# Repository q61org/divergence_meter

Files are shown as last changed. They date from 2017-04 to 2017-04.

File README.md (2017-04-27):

# Divergence Meter Project (by q61.org)

This is yet another divergence meter project.

This project tries to make a divergence meter that look just like the one in the Steins;Gate anime series, by implementing the following features:
- Using tip-less, flat-top nixie tubes (NL902) that look similar to the tubes in the anime.
- Compact dimensions: so that you can hold it on your hand like Suzuha does, and so that you can use the meter for cosplaying.
- A built-in, rechargeable battery; so that Suzuha can take it out of her bag while it is displaying a divergence value.

The result, a completed divergence meter can be seen below.

divergence meter with dr pepper
divergence meter with an anime screen capture

## Files in This Repository

This repository contains schematics, PCB files and a firmware of the divergence meter. Chassis design is left as an exercise to makers (forks and pull requests are welcome!).

The divergence meter is composed of 3 PCBs, and there are 3 PCB filesets in this repository:
- dm_control: A board that controls everything; the motherboard.
- dm_nixiebrd: A serial-to-parallel converter board with nixie drivers. This is the board where nixie tubes are mounted on, and stacks on top of dm_control board.
- dm_topboard: A perfboard-like board that goes on top of the divergence meter. This board does not have any electrical functions, but adds very much to the aesthetics.

dm_control board has a microcontroller, and its firmware is in the following subdirectory:
- dm_firmware: Firmware for dm_control board.

## License

Schematics and PCB, and firmware are licensed under different licenses:
- Schematics and PCB files are licensed under [Creative Commons BY-SA 4.0](https://creativecommons.org/licenses/by-sa/4.0/).
- Firmware is licensed under the BSD license. 

Please see README.md and LICENSE files in respective directories.

## See Also

This project was inspired by following projects:
- [Divergence Meter Project](http://www.mindspring.com/~tomtitor/)
- [世界线变动率探测仪 | Divergence Meter](http://www.nixieclock.org/?cat=219)

## Disclaimer

There is no warranty, expressed or implied, associated with files in this project. Especially there is a high voltage shock hazard which can kill you. Use at your own risk. 

## Author

Kouichi Kuroi (q61.org)
- Twitter: https://twitter.com/q61501331

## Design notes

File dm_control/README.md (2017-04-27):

# dm_control Board

This board is the motherboard of the divergence meter.

The board has the following functionalities on board:
- Lithium-ion battery charger
- 3.7V to 180V DC/DC boost converter
- 3.7V to 3.3V DC/DC buck converter
- Microcontroller (ATmega328P) that controls nixie tubes
- USB to UART converter (FT231X)
- Accurate RTC (DS3234)

## About Power Supplies

You must be careful about power supplies on this board,
as they can be hazardous to you in some ways.

### Lithium-ion Battery Charger

This board has an MCP73831 battery charger chip. You can connect
a lithium-ion battery to connector P2 to make the divergence meter
free from power cords. 
However, you must be careful about what battery you use.

The MCP73831 chip controls only charging from the USB connector; 
it automatically stops charging when the battery is full, 
but it does not stop discharging when the battery is empty.

**There is no overdischarge protection on this board.**
Therefore you **MUST** use a battery with a built-in
overdischarge protection. **DO NOT USE RAW CELLS!**

Connector P2 is a 2-pin PH connector. This is a standard connector
for commonly available pouched LiPo cells. These batteries
usually have protection circuits, but double-check it before 
you actually use one.

### DC/DC Converters

This board has two DC/DC converters on board, a boost converter
that generates 180V for igniting nixie tubes, and a buck converter
that generates 3.3V for microcontroller and other digital chips.

The one that can harm you is, obviously, the boost converter.
Although it can only output some milliamps continuously, it has
2uF of smoothing capacitors (C14 and C15). 
When the converter is powered up without any load, it can charge 
the capacitors to their maximum capacity. This charge will remain 
in the capacitors after the converter is powered down, 
and when you touch them, all the charge can go through you.
This can be very bad.

When handling this board, always make sure that the power is off,
and that capacitors are discharged.

## Disclaimer (again)

There is no warranty, expressed or implied, associated with files in this project. Especially there is a high voltage shock hazard which can kill you. Use at your own risk. 

## License

Schematics and PCB files are licensed under Creative Commons BY-SA 4.0.

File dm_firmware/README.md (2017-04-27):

# dm_firmware

This is a firmware for ATmega chip on dm_control board.

It is intended to be compiled with Atmel Studio 7, but you can also compile it with standard avr-gcc (with some command line options).
You can first burn a bootloader (such as Arduino or Optiboot) onto the ATmega so that firmware upgrade can be done via USB.

## Fuse Settings

This firmware does not handle WDT. WDT must be turned off.

As the firmware controls multiplexing of nixie tubes by 8.192kHz clock
from the RTC, it isn't very strict about clocking the cpu itself.
However, if you use a bootloader, you should set it to use the ceramic
resonator on dm_control board, so that UART communication has less errors.

If you use Arduino bootloader, the following fuse settings is good:
- Extended bits: 0xFD
- High bits: 0xDA
- Low bits: 0xFF

## Functions

The firmware has very limited set of functions.

When you power up the meter, it does a lamp check (cycling from 0 to 9 and dp),
and then displays a divergence value.

When you press SW2 or SW3, the display changes to next preset divergence value.

When you press SW5, it shuffles the display for about 10 seconds and then
goes back to the divergence value.

When you press SW4, it displays current voltage of the battery. When you press SW4 again while shoing the voltage, the meter goes into a demo mode.
In demo mode, divergence value changes every about 20 seconds.

## License

Files in this directory are licensed under BSD license.

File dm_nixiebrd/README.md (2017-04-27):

# dm_nixiebrd Board

This is a serial-to-parallel converter board with nixie drivers.
It is designed for NL-902 or NL-842 nixie tubes.

This board needs a high voltage power to ignite nixie tubes. 
Be careful when handling high voltages. It can kill you.

* How to Connect With dm_control Board

The left half of this board is designed to match with the dm_control board.
You can solder pin headers to P1-P3, and they mate with P4-P6 of dm_control board.

## Mounting Nixie Tubes

This board is designed to use discrete pin sockets to mount nixie tubes.
The sockets should be a "Socket Pin" type which accept 1mm pins for 
socket side and which have 0.5mm pin for pin side.

If you search eBay with keywords "1mm nixie pin" you will get good examples.
And in fact I used pins from eBay for my first divergence meter.

Of course it is also good to modify the board so that it fits any sockets
or direct soldering you would want to use.

## Changing Nixie Tubes

As well as mounting method you can change nixie tubes that this board mounts.
If nixie tubes are rated for nominal currents out of 3mA-4mA range, 
you should change values of R2 and R12 resistors.

## Disclaimer (again)

There is no warranty, expressed or implied, associated with files in this project. Especially there is a high voltage shock hazard which can kill you. Use at your own risk. 

## License

Schematics and PCB files are licensed under Creative Commons BY-SA 4.0.

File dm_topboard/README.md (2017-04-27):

# dm_topboard Board

This is a perfboard-like board that goes on top of a divergence meter.

The board is mostly a 3.15mm-pitch perfboard, except that it has the 
following features to accomodate parts for making it look like the
perfboard on top of the divergence meter in the anime:
- 8 holes with 16mm diameter, where pins of nixie tubes go through (to dm_nixiebrd board).
- 2 sets of 16x 2.54mm-pitch holes in the back of the board, where 16-pin DIP ICs go in.
- 1 pair of 5mm-pitch holes in the front of the board, where a coin-shaped capacitor (or anything else that looks like it) goes in.

Mounting holes are for M2.6 screws.

## License

Files in this directory are licensed under Creative Commons BY-SA 4.0.

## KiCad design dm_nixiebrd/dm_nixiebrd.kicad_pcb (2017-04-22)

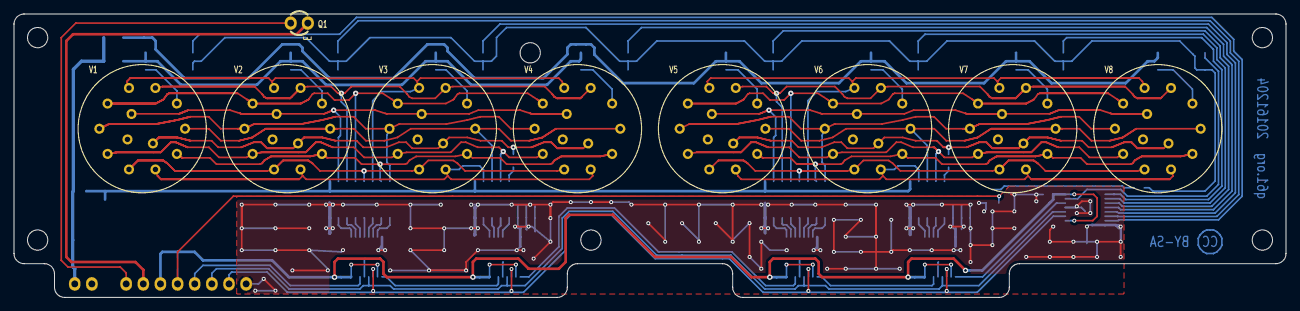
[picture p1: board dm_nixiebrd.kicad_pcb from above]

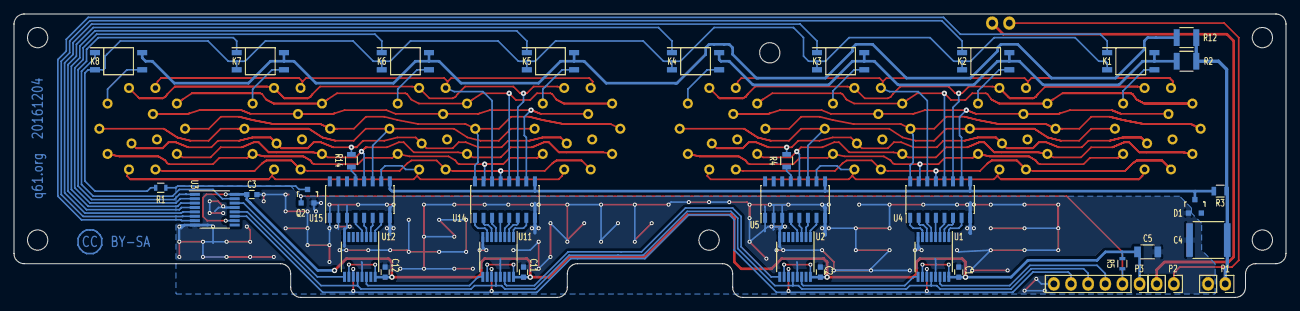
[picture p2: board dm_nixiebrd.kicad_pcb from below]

Board: 2 copper layers, 188.5 x 42.0 mm, 45 parts (36 on the bottom side), 79 nets.

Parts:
C1, C2, C3, C11, C12: 0.1u; C_0603
C4: 1u250V; C_2220
C5: 10u; C_1206
D1: 75V_SOT23; SOT-23
K1, K2, K3, K4, K5, K6, K7, K8: TLP188; Optocoupler_SOP6_4
P1: HV; Pin_Header_Straight_1x02
P2: Opto; Pin_Header_Straight_1x02
P3: Signal; Pin_Header_Straight_1x06
Q1: OptTr; OptoTr_TH_3mm_Pitch2.54mm
Q2: 2N7002; SOT-23
R1: 470; R_0603
R2, R12: 3.3k; R_1210
R3: 220k; R_0805
R4, R14: 47k; R_0805
R5: 100k; R_0603
U1, U2, U3, U11, U12: 74HC595; TSSOP-16_4.4x5mm_Pitch0.65mm
U4, U5, U14, U15: SN75468; SOIC-16_3.9x9.9mm_Pitch1.27mm
V1, V2, V3, V4, V5, V6, V7, V8: NL-841; NL-902

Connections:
+3V3: C1.1, C2.1, C3.1, C5.1, C11.1, C12.1, P3.1, R5.1, U1.10, U1.16, U2.10, U2.16, U3.10, U3.16, U11.10, U11.16, U12.10, U12.16
/A1: K1.4, V1.4
/A2: K2.4, V2.4
/A3: K3.4, V3.4
/A4: K4.4, V4.4
/A5: K5.4, V5.4
/A6: K6.4, V6.4
/A7: K7.4, V7.4
/A8: K8.4, V8.4
/ACOM0: K1.6, K2.6, K3.6, K4.6, R2.2
/ACOM1: K5.6, K6.6, K7.6, K8.6, R12.2
/AN1: K1.1, U3.7
/AN2: K2.1, U3.6
/AN3: K3.1, U3.5
/AN4: K4.1, U3.4
/AN5: K5.1, U3.3
/AN6: K6.1, U3.2
/AN7: K7.1, U3.1
/AN8: K8.1, U3.15
/APWM: P3.2, Q2.1, R5.2
/K0: U4.10, V1.13, V2.13, V3.13, V4.13
/K1: U4.11, V1.5, V2.5, V3.5, V4.5
/K2: U4.12, V1.7, V2.7, V3.7, V4.7
/K3: U4.13, V1.10, V2.10, V3.10, V4.10
/K4: U4.14, V1.6, V2.6, V3.6, V4.6
/K5: U4.15, V1.2, V2.2, V3.2, V4.2
/K6: U4.16, V1.8, V2.8, V3.8, V4.8
/K7: U5.10, V1.1, V2.1, V3.1, V4.1
/K8: U5.11, V1.3, V2.3, V3.3, V4.3
/K9: U5.12, V1.9, V2.9, V3.9, V4.9
/K10: U14.10, V5.13, V6.13, V7.13, V8.13
/K11: U14.11, V5.5, V6.5, V7.5, V8.5
/K12: U14.12, V5.7, V6.7, V7.7, V8.7
/K13: U14.13, V5.10, V6.10, V7.10, V8.10
/K14: U14.14, V5.6, V6.6, V7.6, V8.6
/K15: U14.15, V5.2, V6.2, V7.2, V8.2
/K16: U14.16, V5.8, V6.8, V7.8, V8.8
/K17: U15.10, V5.1, V6.1, V7.1, V8.1
/K18: U15.11, V5.3, V6.3, V7.3, V8.3
/K19: U15.12, V5.9, V6.9, V7.9, V8.9
/KDP: R4.2, V1.11, V2.11, V3.11, V4.11
/KDP1: R14.2, V5.11, V6.11, V7.11, V8.11
/KN0: U1.1, U4.7
/KN1: U1.2, U4.6
/KN2: U1.3, U4.5
/KN3: U1.4, U4.4
/KN4: U1.5, U4.3
/KN5: U1.6, U4.2
/KN6: U1.7, U4.1
/KN7: U2.1, U5.7
/KN8: U2.2, U5.6
/KN9: U2.3, U5.5
/KN10: U11.1, U14.7
/KN11: U11.2, U14.6
/KN12: U11.3, U14.5
/KN13: U11.4, U14.4
/KN14: U11.5, U14.3
/KN15: U11.6, U14.2
/KN16: U11.7, U14.1
/KN17: U12.1, U15.7
/KN18: U12.2, U15.6
/KN19: U12.3, U15.5
/KNDP: U2.4, U5.4
/KNDP1: U12.4, U15.4
/RCLK: P3.4, U1.12, U2.12, U3.12, U11.12, U12.12
/SCLK: P3.5, U1.11, U2.11, U3.11, U11.11, U12.11
/SDIN: P3.3, U1.14
/VPREBIAS: D1.3, R3.2, U4.9, U5.9, U14.9, U15.9
GND: C1.2, C2.2, C3.2, C4.2, C5.2, C11.2, C12.2, D1.1, P1.2, P2.2, P3.6, Q1.1, Q2.2, U1.8, U1.13, U2.8, U2.13, U3.8, U3.13, U4.8, U5.1, U5.2, U5.3, U5.8, U11.8, U11.13, U12.8, U12.13, U14.8, U15.1, U15.2, U15.3, U15.8
HT: C4.1, P1.1, R2.1, R3.1, R12.1
unnamed: K1.3, K2.3, K3.3, K4.3, K5.3, K6.3, K7.3, K8.3, R1.2
unnamed: P2.1, Q1.3
unnamed: Q2.3, R1.1
unnamed: R4.1, U5.13
unnamed: R14.1, U15.13
unnamed: U1.9, U2.14
unnamed: U11.9, U12.14
unnamed: U2.9, U11.14
unnamed: U3.14, U12.9

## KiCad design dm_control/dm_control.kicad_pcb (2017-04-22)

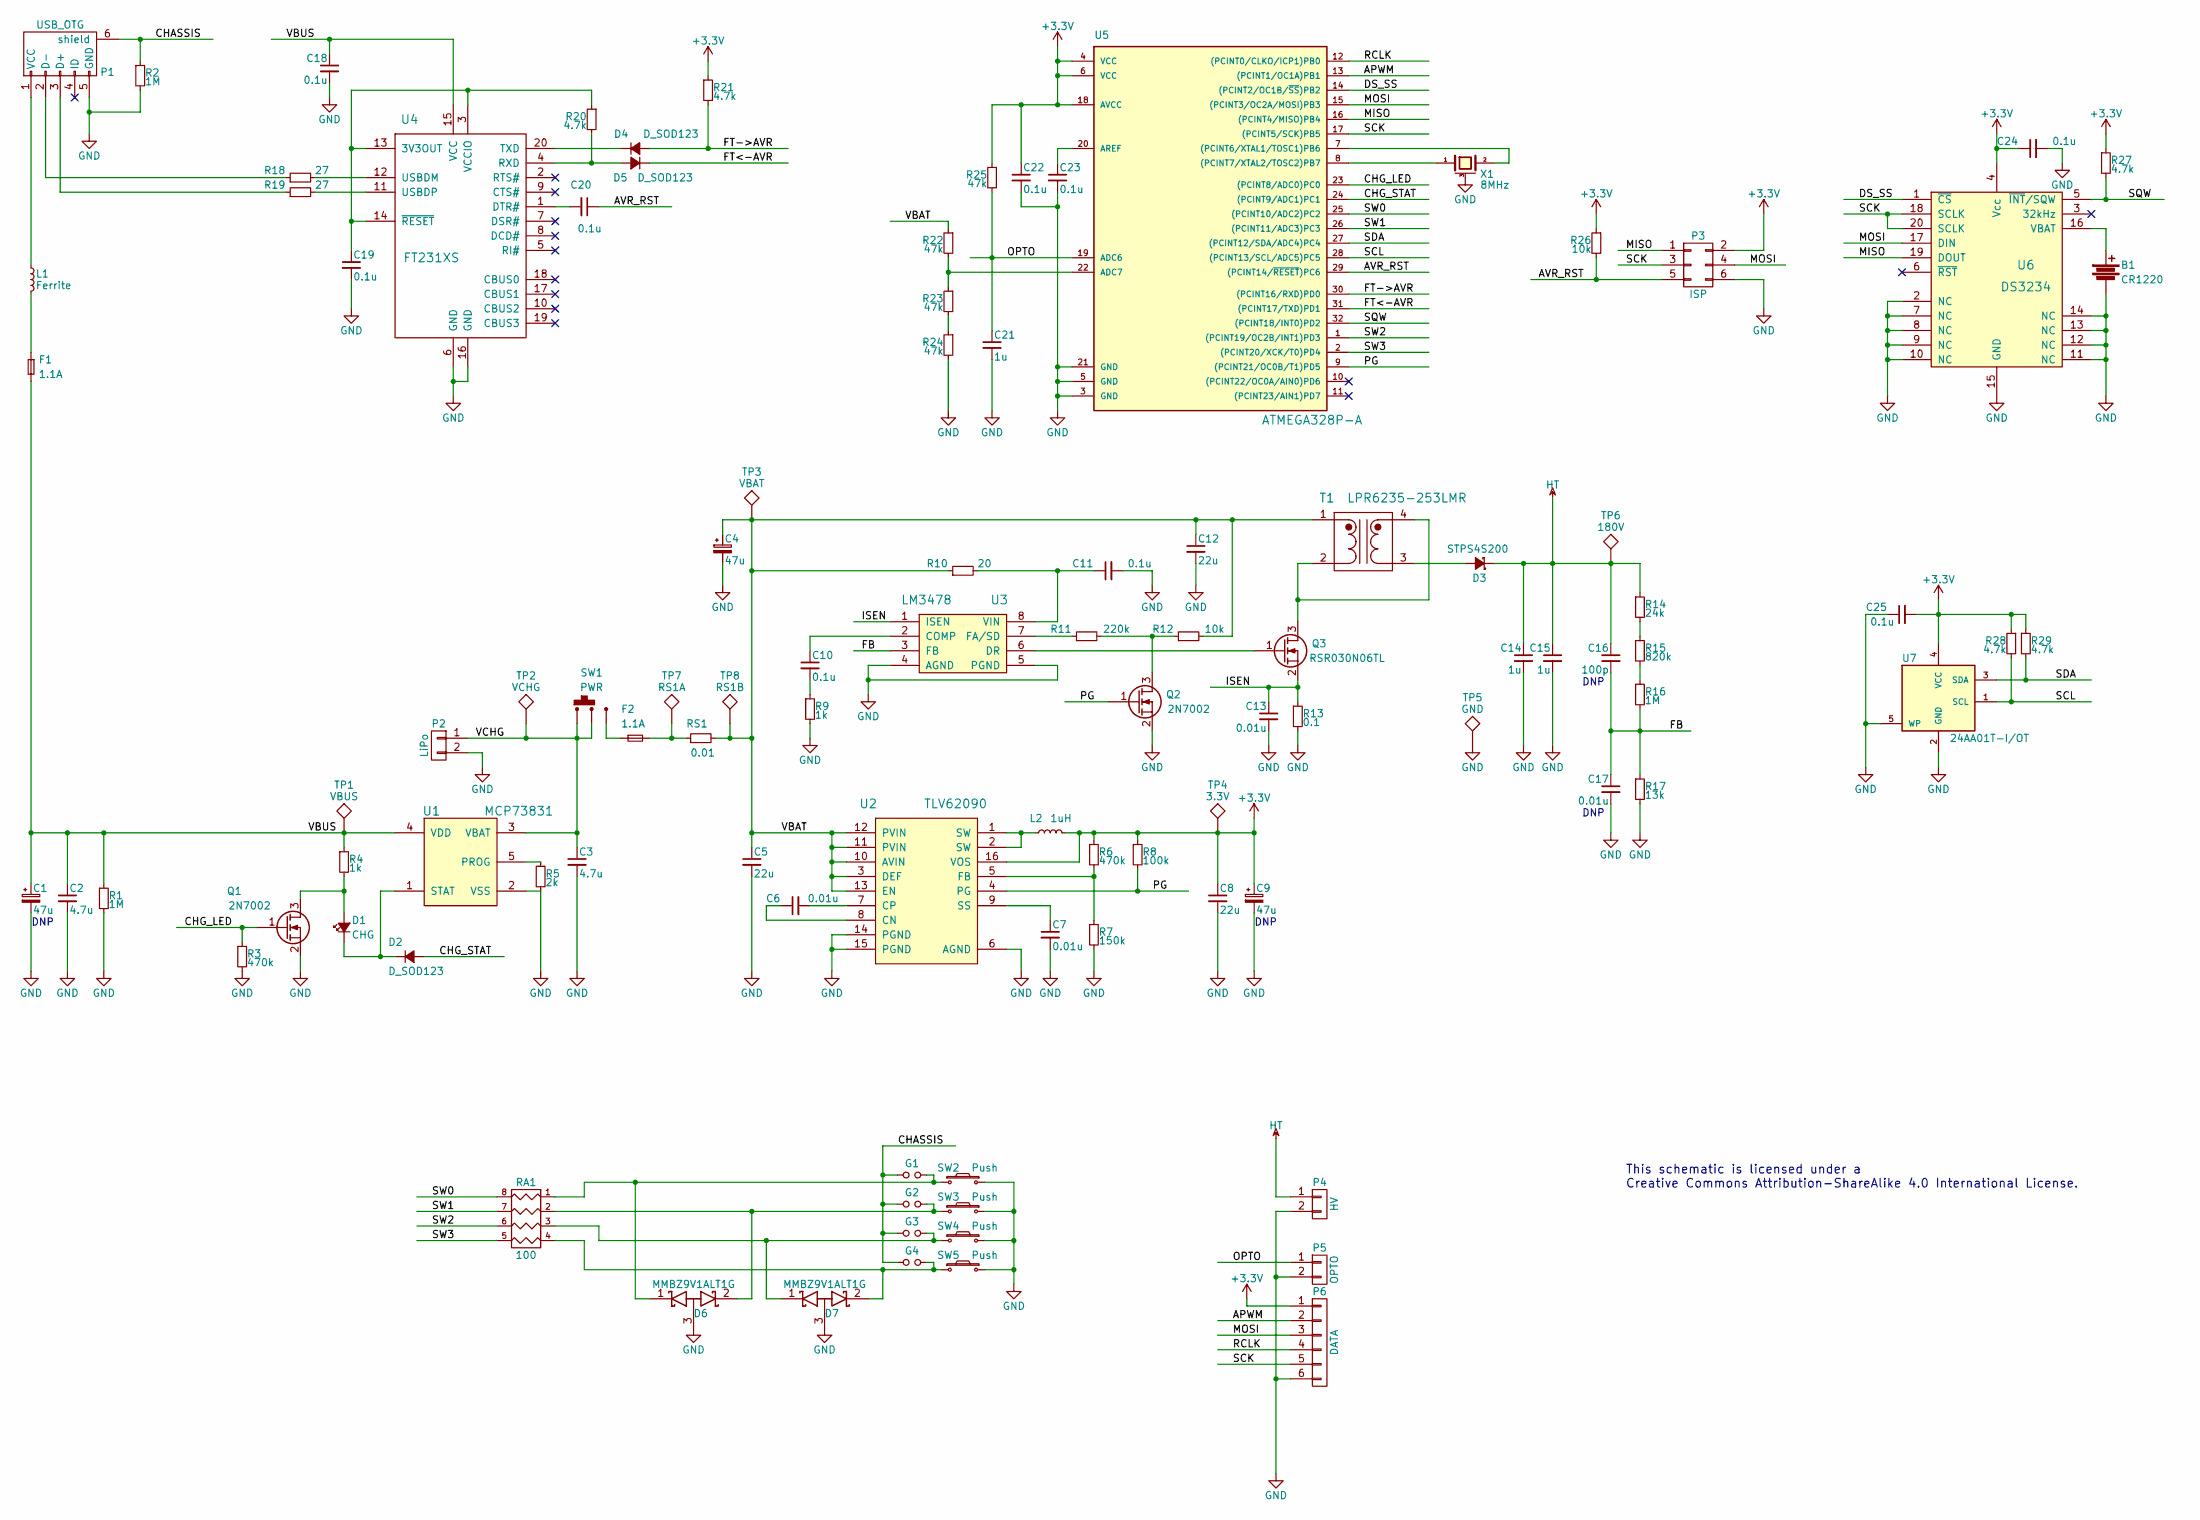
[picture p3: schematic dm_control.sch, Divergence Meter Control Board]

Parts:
B1: CR1220; Battery_CR1220
C1, C4, C9: 47u; C_Radial_D5_L6_P2.5
C2, C3: 4.7u; C_0805
C5, C8, C12: 22u; C_0805
C6, C7, C13, C17: 0.01u; C_0603
C10, C11, C18, C19, C20, C22, C23, C24, C25: 0.1u; C_0603
C14, C15: 1u; C_2220
C16: 100p; C_0805
C21: 1u; C_0603
D1: CHG; LED-3MM
D2, D4, D5: D_SOD123; SOD-123
D3: STPS4S200; SMB_Standard
D6, D7: MMBZ9V1ALT1G; SOT-23
F1, F2: 1.1A; R_1210
G1, G2, G3, G4: Jumper_NO_Small; SparkGap_0.2mm
L1: Ferrite; R_0805
L2: 1uH; Inductor_Taiyo-Yuden_NR-40xx
P1: USB_OTG; USB_Micro-B
P2: LiPo; Conn_S2B-PH-SM4-TB
P3: ISP; Pin_Header_Straight_2x03
P4: HV; Pin_Header_Straight_1x02
P5: OPTO; Pin_Header_Straight_1x02
P6: DATA; Pin_Header_Straight_1x06
Q1, Q2: 2N7002; SOT-23
Q3: RSR030N06TL; SOT-23
R1, R2, R16: 1M; R_0603
R3, R6: 470k; R_0603
R4, R9: 1k; R_0603
R5: 2k; R_0603
R7: 150k; R_0603
R8: 100k; R_0603
R10: 20; R_0603
R11: 220k; R_0603
R12, R26: 10k; R_0603
R13: 0.1; R_1206
R14: 24k; R_0603
R15: 820k; R_0603
R17: 13k; R_0603
R18, R19: 27; R_0603
R20, R21, R27, R28, R29: 4.7k; R_0603
R22, R23, R24, R25: 47k; R_0603
RA1: 100; R_Array_Convex_4x0603
RS1: 0.01; R_0603
SW1: PWR; PINHEAD1-3
SW2, SW3, SW4, SW5: Push; SW_Tactile_SPST_Angled
T1: LPR6235-253LMR; Transformer_CTX02-18714-R
TP1: VBUS; Pin_Header_Straight_1x01
TP2: VCHG; Pin_Header_Straight_1x01
TP3: VBAT; Pin_Header_Straight_1x01
TP4: 3.3V; Pin_Header_Straight_1x01
TP5: GND; Pin_Header_Straight_1x01
TP6: 180V; Pin_Header_Straight_1x01
TP7: RS1A; Pin_Header_Straight_1x01
TP8: RS1B; Pin_Header_Straight_1x01
U1: MCP73831; SOT-23-5
U2: TLV62090; QFN-16-1EP_3x3mm_Pitch0.5mm
U3: LM3478; MSOP-8_3x3mm_Pitch0.65mm
U4: FT231XS; SSOP-20_4.0x8.5mm_Pitch0.635mm
U5: ATMEGA328P-A; TQFP-32_7x7mm_Pitch0.8mm
U6: DS3234; SOIC-20W_7.5x12.8mm_Pitch1.27mm
U7: 24AA01T-I/OT; SOT-23-5
X1: 8MHz; Ceralock_CSTCE-G

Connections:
+3V3: C8.1, C9.1, C22.1, C24.1, C25.2, L2.2, P3.2, P6.1, R6.1, R8.1, R21.1, R25.1, R26.1, R27.1, R28.1, R29.1, TP4.1, U2.16 (VOS), U5.4 (VCC), U5.6 (VCC), U5.18 (AVCC), U6.4 (Vcc), U7.4 (VCC)
/APWM: P6.2, U5.13 ((PCINT1/OC1A)PB1)
/AVR_RST: C20.1, P3.5, R26.2, U5.29 ((PCINT14/~RESET~)PC6)
/CHASSIS: G1.2, G2.2, G3.2, G4.2, P1.6 (shield), R2.1, SW1.4, SW2.3, SW2.4, SW3.3, SW3.4, SW4.3, SW4.4, SW5.3, SW5.4
/CHG_LED: Q1.1 (G), R3.1, U5.23 ((PCINT8/ADC0)PC0)
/CHG_STAT: D2.2 (A), U5.24 ((PCINT9/ADC1)PC1)
/DS_SS: U5.14 ((PCINT2/OC1B/~SS~)PB2), U6.1 (~CS)
/FB: C16.2, C17.1, R16.2, R17.1, U3.3 (FB)
/FT->AVR: D4.2 (A), R21.2, U5.30 ((PCINT16/RXD)PD0)
/FT<-AVR: D5.1 (K), U5.31 ((PCINT17/TXD)PD1)
/ISEN: C13.1, Q3.2 (S), R13.1, U3.1 (ISEN)
/MISO: P3.1, U5.16 ((PCINT4/MISO)PB4), U6.19 (DOUT)
/MOSI: P3.4, P6.3, U5.15 ((PCINT3/OC2A/MOSI)PB3), U6.17 (DIN)
/OPTO: C21.1, P5.1, R25.2, U5.19 (ADC6)
/PG: Q2.1 (G), R8.2, U2.4 (PG), U5.9 ((PCINT21/OC0B/T1)PD5)
/RCLK: P6.4, U5.12 ((PCINT0/CLKO/ICP1)PB0)
/SCK: P3.3, P6.5, U5.17 ((PCINT5/SCK)PB5), U6.18 (SCLK), U6.20 (SCLK)
/SCL: R28.2, U5.28 ((PCINT13/SCL/ADC5)PC5), U7.1 (SCL)
/SDA: R29.2, U5.27 ((PCINT12/SDA/ADC4)PC4), U7.3 (SDA)
/SQW: R27.2, U5.32 ((PCINT18/INT0)PD2), U6.5 (~INT~/SQW)
/SW0: RA1.8 (R1), U5.25 ((PCINT10/ADC2)PC2)
/SW1: RA1.7 (R2), U5.26 ((PCINT11/ADC3)PC3)
/SW2: RA1.6 (R3), U5.1 ((PCINT19/OC2B/INT1)PD3)
/SW3: RA1.5 (R4), U5.2 ((PCINT20/XCK/T0)PD4)
/VBAT: C4.1, C5.1, C12.1, R10.1, R12.2, R22.1, RS1.2, T1.1, TP3.1, TP8.1, U2.3 (DEF), U2.10 (AVIN), U2.11 (PVIN), U2.12 (PVIN), U2.13 (EN)
/VBUS: C1.1, C2.1, C18.1, F1.2, R1.1, R4.1, TP1.1, U1.4 (VDD), U4.15 (VCC)
/VCHG: C3.1, P2.1, SW1.1, SW1.2, TP2.1, U1.3 (VBAT)
GND: B1.2, C1.2, C2.2, C3.2, C4.2, C5.2, C7.2, C8.2, C9.2, C11.2, C12.2, C13.2, C14.2, C15.2, C17.2, C18.2, C19.2, C21.2, C22.2, C23.2, C24.2, C25.1, D6.3 (A), D7.3 (A), P1.5 (GND), P2.2, P3.6, P4.2, P5.2, P6.6, Q1.2 (S), Q2.2 (S), R1.2, R2.2, R3.2, R5.2, R7.2, R9.2, R13.2, R17.2, R24.2, SW2.2, SW3.2, SW4.1, SW5.1, TP5.1, U1.2 (VSS), U2.6 (AGND), U2.14 (PGND), U2.15 (PGND), U3.4 (AGND), U3.5 (PGND), U4.6 (GND), U4.16 (GND), U5.3 (GND), U5.5 (GND), U5.21 (GND), U6.2 (NC), U6.7 (NC), U6.8 (NC), U6.9 (NC), U6.10 (NC), U6.11 (NC), U6.12 (NC), U6.13 (NC), U6.14 (NC), U6.15 (GND), U7.2 (GND), U7.5 (WP), X1.3 (case)
HT: C14.1, C15.1, C16.1, D3.1 (K), P4.1, R14.1, TP6.1
unnamed: B1.1, U6.16 (VBAT)
unnamed: C6.1, U2.8 (CN)
unnamed: C6.2, U2.7 (CP)
unnamed: C7.1, U2.9 (SS)
unnamed: C10.1, U3.2 (COMP)
unnamed: C10.2, R9.1
unnamed: C11.1, R10.2, U3.8 (VIN)
unnamed: C19.1, R20.1, U4.3 (VCCIO), U4.13 (3V3OUT), U4.14 (~RESET)
unnamed: C20.2, U4.1 (DTR#)
unnamed: C23.1, U5.20 (AREF)
unnamed: D1.1 (K), D2.1 (K), U1.1 (STAT)
unnamed: D1.2 (A), Q1.3 (D), R4.2
unnamed: D3.2 (A), T1.3
unnamed: D4.1 (K), U4.20 (TXD)
unnamed: D5.2 (A), R20.2, U4.4 (RXD)
unnamed: D6.1 (K), G1.1, RA1.1, SW2.1
unnamed: D6.2 (K), G2.1, RA1.2, SW3.1
unnamed: D7.1 (K), G3.1, RA1.3, SW4.2
unnamed: D7.2 (K), G4.1, RA1.4, SW5.2
unnamed: F1.1, L1.2
unnamed: F2.1, SW1.3
unnamed: F2.2, RS1.1, TP7.1
unnamed: L1.1, P1.1 (VCC)
unnamed: L2.1, U2.1 (SW), U2.2 (SW)
unnamed: P1.2 (D-), R18.1
unnamed: P1.3 (D+), R19.1
unnamed: Q2.3 (D), R11.2, R12.1
unnamed: Q3.1 (G), U3.6 (DR)
unnamed: Q3.3 (D), T1.2, T1.4
unnamed: R5.1, U1.5 (PROG)
unnamed: R6.2, R7.1, U2.5 (FB)
unnamed: R11.1, U3.7 (FA/SD)
unnamed: R14.2, R15.1
unnamed: R15.2, R16.1
unnamed: R18.2, U4.12 (USBDM)
unnamed: R19.2, U4.11 (USBDP)
unnamed: R22.2, R23.1, U5.22 (ADC7)
unnamed: R23.2, R24.1
unnamed: U5.7 ((PCINT6/XTAL1/TOSC1)PB6), X1.2
unnamed: U5.8 ((PCINT7/XTAL2/TOSC2)PB7), X1.1

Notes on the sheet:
This schematic is licensed under a Creative Commons Attribution-ShareAlike 4.0 International License.
DNP

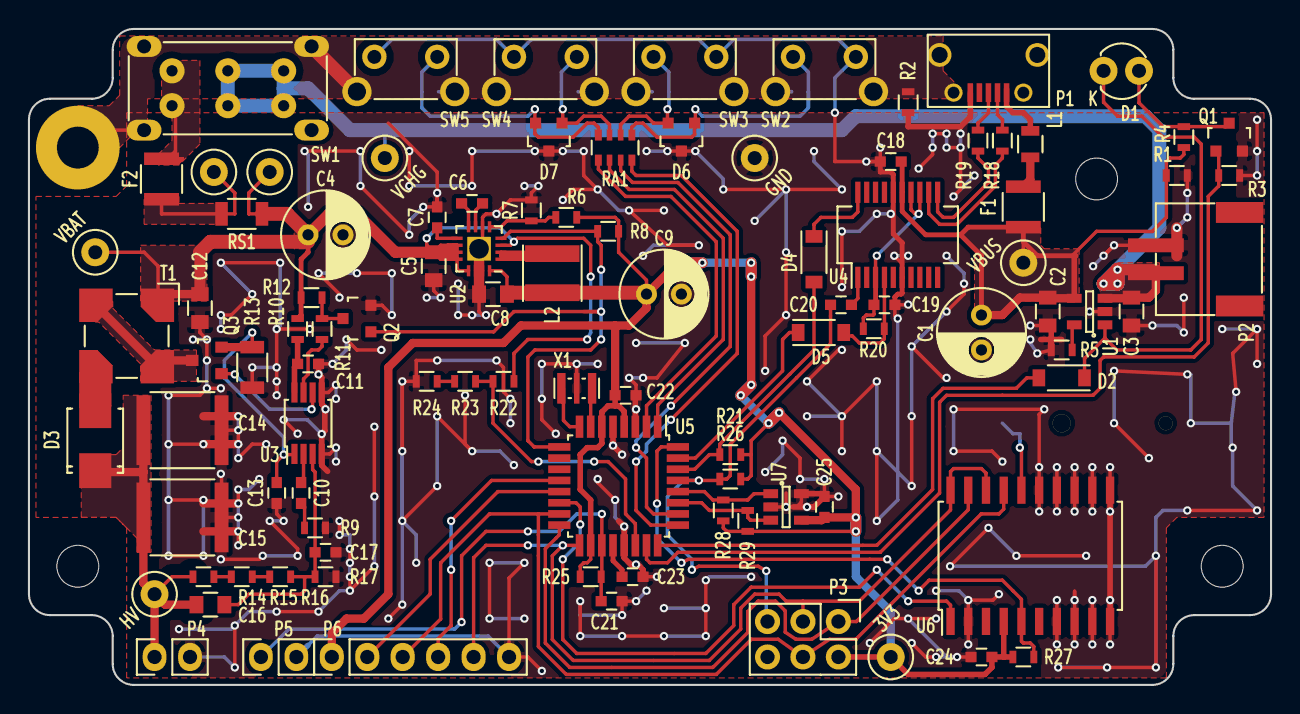
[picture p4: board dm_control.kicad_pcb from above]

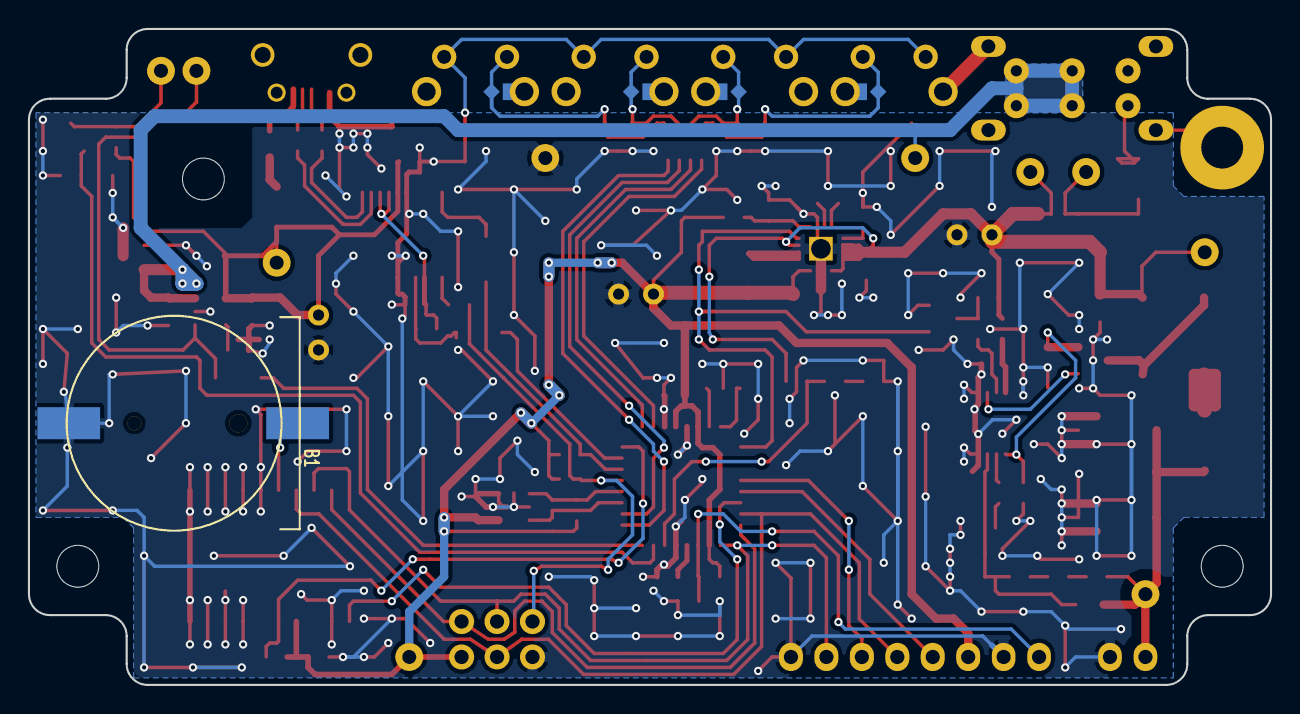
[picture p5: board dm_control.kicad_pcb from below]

Board: 2 copper layers, 89.0 x 47.0 mm, 103 parts (5 on the bottom side), 69 nets.

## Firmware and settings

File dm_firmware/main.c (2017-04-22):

/*
  Firmware for Divergence Meter

  Copyright (c) 2017, Kouichi Kuroi (q61.org)
  All rights reserved.

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
  THIS SOFTWARE IS PROVIDED BY THE COPYRIGHT HOLDERS AND CONTRIBUTORS "AS IS" AND
  ANY EXPRESS OR IMPLIED WARRANTIES, INCLUDING, BUT NOT LIMITED TO, THE IMPLIED
  WARRANTIES OF MERCHANTABILITY AND FITNESS FOR A PARTICULAR PURPOSE ARE
  DISCLAIMED. IN NO EVENT SHALL Kouichi Kuroi BE LIABLE FOR ANY
  DIRECT, INDIRECT, INCIDENTAL, SPECIAL, EXEMPLARY, OR CONSEQUENTIAL DAMAGES
  (INCLUDING, BUT NOT LIMITED TO, PROCUREMENT OF SUBSTITUTE GOODS OR SERVICES;
  LOSS OF USE, DATA, OR PROFITS; OR BUSINESS INTERRUPTION) HOWEVER CAUSED AND
  ON ANY THEORY OF LIABILITY, WHETHER IN CONTRACT, STRICT LIABILITY, OR TORT
  (INCLUDING NEGLIGENCE OR OTHERWISE) ARISING IN ANY WAY OUT OF THE USE OF THIS
  SOFTWARE, EVEN IF ADVISED OF THE POSSIBILITY OF SUCH DAMAGE.
*/

//#define F_CPU		8000000

#include <avr/io.h>
#include <avr/interrupt.h>
#include <avr/eeprom.h>
#include <avr/pgmspace.h>
#include <util/delay.h>
#include <stdlib.h>

#define _nop()  __asm__("nop\n\t")


// ======== PORT MAPPING ========
// PB0 -> 595 LATCH CLK
// PB1 -> (PWM) Optocoupler Cathodes
// PB2 -> RTC Chip Select
// PB3 -> (SPI) MOSI
// PB4 <- (SPI) MISO
// PB5 -> (SPI) SCK
// PC0 -> Charge LED Inhibit
// PC1 <- Charge Status (PU)
// PC2 <- Switch 1 (PU)
// PC3 <- Switch 2 (PU)
// PC4 <> (I2C) SDA
// PC5 <> (I2C) SCL
// PD0 <- (UART) RxD
// PD1 -> (UART) TxD
// PD2 <- RTC SQW
// PD3 <- Switch 3 (PU)
// PD4 <- Switch 4 (PU)
// PD5 <- Power Good
// PD6    NC
// PD7    NC
// ADC6 <- Opto Transistor
// ADC7 <- VBAT

#define DDRB_INIT()		0x2f
#define PORTB_INIT()	0x10
#define DDRC_INIT()		0x01
#define PORTC_INIT()	0x0e
#define DDRD_INIT()		0x00
#define PORTD_INIT()	0x18

#define PORT_RTC_CS_HIGH()			PORTB |= 0x04
#define PORT_RTC_CS_LOW()			PORTB &= 0xfb
#define PORT_595_LATCH_HIGH()		PORTB |= 0x01
#define PORT_595_LATCH_LOW()		PORTB &= 0xfe
#define PORT_OPTO_CATHODE_HIGH()	PORTB |= 0x02
#define PORT_OPTO_CATHODE_LOW()		PORTB &= 0xfd
#define PORT_CHARGE_LED_INHIBIT()	PORTC |= 1
#define PORT_CHARGE_LED_ALLOW()		PORTC &= 0xfe
#define PIN_SWITCH_1()				(PINC & 0x04)
#define PIN_SWITCH_2()				(PINC & 0x08)
#define PIN_SWITCH_3()				(PIND & 0x08)
#define PIN_SWITCH_4()				(PIND & 0x10)

#define SERIAL_BAUD_RATE			9600
#define SERIAL_UBRR					(F_CPU / (16UL * SERIAL_BAUD_RATE)) - 1

volatile static uint8_t g_subsec;		// 256th of a second
volatile static uint8_t g_subsubsec;	// 8192th of a second
volatile static uint8_t g_tmr_decr;		// counts down 8 times a second
volatile static uint8_t g_tmr_relay_intvl;

struct nixiedigit_t {
	uint8_t current;
	uint8_t target;
	uint8_t phase;
	uint8_t phase_acc;
};
static struct nixiedigit_t g_nixiedata[8];


struct settings_t {
	uint8_t transition;
	uint8_t colon_mode;
	uint8_t colon_speed;
	uint8_t flags0;
	uint8_t checksum;
};
#define SETTINGS_T_NUMBYTES 5
enum {
	TRANSITION_NONE = 0,
	TRANSITION_CROSSFADE,
	TRANSITION_RELAY,
	TRANSITION_MAX
};
static struct settings_t g_settings;

#define EEPROM_ADDR_SETTINGS 16


static uint8_t g_btntimer[4];
static uint8_t g_brightness_target;
static uint8_t g_brightness_current;
static uint8_t g_transition;


typedef uint8_t bool;
#define true 1
#define false 0

static bool g_demo_ison;
static uint8_t g_demo_phase;
static uint8_t g_demo_decr;


uint8_t spi_write_sync(uint8_t dt)
{
	SPDR = dt;
	while ((SPSR & (1 << SPIF)) == 0) {
		;
	}
	return (SPDR);
}


uint8_t swap_bit_order(uint8_t n)
{
	uint8_t rt = 0;
	for (uint8_t i = 0; i < 8; i++) {
		rt <<= 1;
		rt |= (n & 1) ? 1 : 0;
		n >>= 1;
	}
	return (rt);
}



void nixie_output_raw(uint8_t a_mask, uint8_t kl_hi, uint8_t kl_lo, uint8_t kr_hi, uint8_t kr_lo)
{
	PORT_595_LATCH_LOW();
	spi_write_sync(a_mask);
	spi_write_sync(kr_hi);
	spi_write_sync(kr_lo);
	spi_write_sync(kl_hi);
	spi_write_sync(kl_lo);
	PORT_595_LATCH_HIGH();
}

void nixie_output(uint8_t digit, uint8_t num_l, uint8_t num_r)
{
	if (digit == 0) {
		nixie_output_raw(0, 0xff, 0xff, 0xff, 0xff);
	} else {
		uint8_t al, ar;
		uint8_t kl_hi, kl_lo;
		uint8_t kr_hi, kr_lo;

		if (num_l > 10) {
			al = 0;
			kl_hi = kl_lo = 255;
		} else {
			al = 0x80 >> (digit - 1);
			if (num_l < 7) {
				kl_hi = 0;
				kl_lo = 2 << num_l;
			} else {
				kl_hi = 1 << (num_l - 6);
				kl_lo = 0;
			}
		}
		if (num_r > 10) {
			ar = 0;
			kr_hi = kr_lo = 255;
		} else {
			ar = 0x08 >> (digit - 1);
			if (num_r < 7) {
				kr_hi = 0;
				kr_lo = 2 << num_r;
			} else {
				kr_hi = 1 << (num_r - 6);
				kr_lo = 0;
			}
		}

		nixie_output_raw(al | ar, kl_hi, kl_lo, kr_hi, kr_lo);
	}
}


void nixie_blank_leading_zeros(uint8_t count)
{
}


void nixie_set_next_digit(uint8_t digit, uint8_t val)
{
	struct nixiedigit_t *dp = &g_nixiedata[digit & 7];

	if (dp->target == val) {
		return;
	}

	switch (g_transition) {
	case TRANSITION_CROSSFADE:
	case TRANSITION_RELAY:
		if (dp->current == dp->target) {
			dp->target = val;
		} else {
			dp->current = dp->target;
			dp->target = val;
			dp->phase = 0;
			dp->phase_acc = 0;
		}
		break;
	default:
		dp->current = dp->target = val;
		dp->phase = 0;
		break;
	}
}


void btns_update()
{
	for (uint8_t i = 0; i < 4; i++) {
		uint8_t dt = 0;
		switch (i) {
			case 0: dt = PIN_SWITCH_1(); break;
			case 1: dt = PIN_SWITCH_2(); break;
			case 2: dt = PIN_SWITCH_3(); break;
			case 3: dt = PIN_SWITCH_4(); break;
		}
		if (dt) {
			g_btntimer[i] = 0;
		} else {
			if (g_btntimer[i] < 255) {
				g_btntimer[i]++;
			}
		}
	}
}

uint8_t btn_state(uint8_t index)
{
	return (g_btntimer[index & 3]);
}

uint8_t btn_state_is_clicked(uint8_t index)
{
	return (btn_state(index) == 1);
}

uint8_t btn_state_is_down(uint8_t index)
{
	return (btn_state(index) >= 1);
}

uint8_t btn_state_is_held_down(uint8_t index)
{
	return (btn_state(index) >= 128);
}

bool btn_state_some_btn_is_clicked()
{
	return (btn_state_is_clicked(0) || btn_state_is_clicked(1) || btn_state_is_clicked(2) || btn_state_is_clicked(3));
}


void rtc_write(uint8_t addr, const uint8_t *src, uint8_t length)
{
	if (length < 1) {
		return;
	}

	PORT_RTC_CS_LOW();
	_nop();
	spi_write_sync(addr | 0x80);
	while (length-- > 0) {
		spi_write_sync(*src++);
	}
	_nop();
	PORT_RTC_CS_HIGH();
}


void rtc_read(uint8_t addr, uint8_t *dst, uint8_t length)
{
	if (length < 1) {
		return;
	}

	PORT_RTC_CS_LOW();
	_nop();
	spi_write_sync(addr);
	while (length-- > 0) {
		*dst++ = spi_write_sync(0);
	}
	_nop();
	PORT_RTC_CS_HIGH();
}



enum {
	ADC_SEL_OPTO = 0,
	ADC_SEL_VBAT
};
static volatile uint8_t g_adc_current_sel;

void adc_read_start(uint8_t sel)
{
	uint8_t adcsrc = (sel == ADC_SEL_OPTO) ? 6 : 7;
	g_adc_current_sel = sel;
	ADMUX = (1 << REFS0) | (1 << ADLAR) | adcsrc; // Vcc ref, left justify
	ADCSRA |= (1 << ADSC);
}

volatile uint8_t adc_is_reading_what()
{
	return (g_adc_current_sel);
}
volatile uint8_t adc_is_reading()
{
	return (ADCSRA & (1 << ADSC));
}

volatile uint8_t adc_read_result()
{
	return (ADCH);
}

volatile uint16_t adc_read_result_16()
{
	uint16_t result = ADCL;
	result |= (uint16_t)ADCH << 8;
	return (result);
}



void brightness_set(uint8_t val, bool immediate)
{
	if (immediate) {
		g_brightness_current = val;
	}
	g_brightness_target = val;
}



uint8_t settings_serialize_get_byte(const struct settings_t *src, uint8_t index)
{
	uint8_t rt = 0;
	switch (index) {
		case 0: rt = src->transition; break;
		case 1: rt = src->colon_mode; break;
		case 2: rt = src->colon_speed; break;
		case 3: rt = src->flags0; break;
		case 4: rt = src->checksum; break;
	}
	return (rt);
}

void settings_deserialize_put_byte(struct settings_t *dst, uint8_t index, uint8_t data)
{
	switch (index) {
		case 0: dst->transition = data; break;
		case 1: dst->colon_mode = data; break;
		case 2: dst->colon_speed = data; break;
		case 3: dst->flags0 = data; break;
		case 4: dst->checksum = data; break;
	}
}


uint8_t settings_calc_checksum(const struct settings_t *src)
{
	uint8_t rt = 0x34;
	for (uint8_t i = 0; i < SETTINGS_T_NUMBYTES - 1; i++) {
		uint8_t dt = settings_serialize_get_byte(src, i);
		uint8_t msb = (rt & 0x80) ? 1 : 0;
		rt <<= 1;
		rt |= msb;
		rt ^= dt;
	}
	return (rt);
}


bool settings_read(struct settings_t *dst)
{
	for (uint8_t i = 0; i < SETTINGS_T_NUMBYTES; i++) {
		uint8_t dt = eeprom_read_byte((uint8_t*)(EEPROM_ADDR_SETTINGS + i));
		settings_deserialize_put_byte(dst, i, dt);
	}
	uint8_t chksum = settings_calc_checksum(dst);
	return (chksum == dst->checksum);
}


void settings_write(const struct settings_t *src)
{
	for (uint8_t i = 0; i < SETTINGS_T_NUMBYTES; i++) {
		uint8_t dt;
		if (i < SETTINGS_T_NUMBYTES - 1) {
			dt = settings_serialize_get_byte(src, i);
			} else {
			dt = settings_calc_checksum(src);
		}
		
		uint8_t *addr = (uint8_t*)(EEPROM_ADDR_SETTINGS + i);
		uint8_t cd = eeprom_read_byte(addr);
		if (cd != dt) {
			eeprom_write_byte(addr, dt);
		}
	}
}


void settings_init(struct settings_t *dst)
{
	dst->transition = TRANSITION_NONE;
	dst->colon_speed = 1;
	dst->flags0 = 0;
}



ISR(INT0_vect)
{ // called 8k times a second
	static uint8_t s_nixie_digit;

	++g_subsubsec;
	g_subsubsec &= 31;
	if (g_subsubsec == 0) {
		++g_subsec;
		if ((g_subsec & 31) == 0) {
			if (g_tmr_decr > 0) {
				--g_tmr_decr;
			}
		}
	}
	
	switch (g_subsubsec & 7) {
	case 0:
		if (++s_nixie_digit > 3) {
			s_nixie_digit = 0;
		}
		{
			struct nixiedigit_t *dp = &g_nixiedata[s_nixie_digit];
			uint8_t val_l = g_nixiedata[s_nixie_digit].current;
			uint8_t val_r = g_nixiedata[s_nixie_digit + 4].current;
			nixie_output(s_nixie_digit + 1, val_l, val_r);
		}
		break;
	case 7:
		nixie_output(0, 255, 255);
		break;
	}

	if (((g_subsec & 3) == 0) && (g_subsubsec == 1)) {
		bool doUpdate = false;
		if (g_brightness_target > g_brightness_current) {
			++g_brightness_current;
			doUpdate = true;
		} else if (g_brightness_target < g_brightness_current) {
			--g_brightness_current;
			doUpdate = true;
		}
		if (doUpdate) {
			OCR1A = ((uint16_t)g_brightness_current * g_brightness_current) >> 8;
		}
	}
}


void setup()
{
	DDRB = DDRB_INIT();
	PORTB = PORTB_INIT();
	DDRC = DDRC_INIT();
	PORTC = PORTC_INIT();
	DDRD = DDRD_INIT();
	PORTD = PORTD_INIT();

	PORT_RTC_CS_HIGH();

	// init global vars
	for (uint8_t i = 0; i < 4; i++) {
		struct nixiedigit_t *dp = &g_nixiedata[i];
		dp->current = dp->target = dp->phase = 0;
	}
	g_transition = TRANSITION_NONE;
	g_tmr_relay_intvl = 0;
	g_brightness_current = g_brightness_target = 255;

	// init spi
	SPCR = (1 << SPE) | (1 << MSTR) | (1 << CPOL) | (1 << CPHA) | (1 << SPR0);  // master, Mode 3, F_CPU / 16

	// init PWM
	// Fast PWM mode, Clear on compare match, Set at bottom, CLK / 1024
	TCCR1A = (1 << COM1A1) | (1 << WGM10);
	TCCR1B = (1 << WGM12) | (1 << CS11) | (1 << CS10);
	OCR1A = 255;

	// init Serial
	//UBRR0 = SERIAL_UBRR;
	//UCSR0B = (1 << RXEN0) | (1 << TXEN0);

	// init RTC
	uint8_t dt;
	dt = 0x18;
	rtc_write(0x0e, &dt, 1); // enable square wave output, 8192Hz
	dt = 0x00;
	rtc_write(0x0f, &dt, 1); // disable battery-backed 32kHz output

	// init pin change interrupt
	EICRA = (1 << ISC01) | (1 << ISC00); // interrupt on rising edge
	EIMSK = (1 << INT0);

	// init ADC
	ADCSRA = (1 << ADEN) | (1 << ADPS2) | (1 << ADPS1) | (1 << ADPS0); // enable ADC
	// enable interrupts
	sei();
}




#define AVG_VAL_HISTORY_SIZE	16
#define AVG_VAL_HISTORY_SIZE_SHIFT	4
struct avg_val_16 {
	uint16_t val_history[AVG_VAL_HISTORY_SIZE];
	uint8_t history_pos;
};

void avg_val_16_accum(struct avg_val_16 *val, uint16_t accum)
{
	if (++val->history_pos >= AVG_VAL_HISTORY_SIZE) {
		val->history_pos = 0;
	}
	val->val_history[val->history_pos] = accum;
}
uint16_t avg_val_val(struct avg_val_16 *val)
{
	uint32_t rt = 0;
	for (uint8_t i = 0; i < AVG_VAL_HISTORY_SIZE; i++) {
		rt += val->val_history[i];
	}
	rt >>= AVG_VAL_HISTORY_SIZE_SHIFT;
	return ((uint16_t)rt);
}
uint16_t avg_val_sum(struct avg_val_16 *val)
{
	uint32_t rt = 0;
	for (uint8_t i = 0; i < AVG_VAL_HISTORY_SIZE; i++) {
		rt += val->val_history[i];
	}
	return ((uint16_t)rt);
}




enum {
	DISP_MODE_RTC = 0,
	DISP_MODE_DIV,
	DISP_MODE_RANDOM,
	DISP_MODE_SET_HOUR,
	DISP_MODE_SET_MIN,
	DISP_MODE_SET_TRANSITION,
	DISP_MODE_VOLTAGE,
	DISP_MODE_FIXED
};

#define PRESET_DIV_COUNT 22
PROGMEM const uint32_t g_preset_div[PRESET_DIV_COUNT] = {
	 328403,  334581,  337187,  337199,  337337,  409031, 409420, 409431,
     456903,  456914,  456923,  523299,  523307,  571015, 571024, 571046, 
	1048596, 1048728, 1130205, 1130238, 1130246,  0
};

int main(void)
{
	// hardware setup
	setup();

	// seed random
	{
		unsigned char dt[4];
		rtc_read(0, dt, 4);
		unsigned long seedval = 0;
		for (uint8_t i = 0; i < 4; i++) {
			seedval <<= 8;
			seedval |= dt[i];
		}
		srandom(seedval);
	}


	// lamp check
	for (uint8_t i = 0; i < 12; i++) {
		for (uint8_t dig = 0; dig < 8; dig++) {
			nixie_set_next_digit(dig, (i < 11) ? i : 0);
		}
		if (i == 11) break;
		_delay_ms(100);
	}
	PORT_CHARGE_LED_INHIBIT();


	uint8_t s_last_subsec = 0;
	uint8_t s_last_sec = 0;
	uint8_t s_subsec_zero = 0;
	uint8_t s_disp_mode = 0;
	uint8_t rtcdata[3];
	uint8_t rtc_subsec = 0;
	uint8_t rtc_doset = 0;
	uint8_t settings_doset = 0;
	uint8_t subsec_input_flasher = 0;

	uint8_t s_demo_subsec = 0;
	uint8_t s_demo_sec = 0;
	uint8_t s_demo_phase = 0;
	uint8_t s_random_duration = 0;
	uint32_t s_random_value = 0;
	uint16_t s_adc_value = 0;
	uint8_t s_adc_count = 0;
	
	uint8_t s_div_pos = 0;
	uint32_t s_div_value = pgm_read_dword(&g_preset_div[s_div_pos]);
	
	
	struct avg_val_16 s_adc_val;
	s_disp_mode = DISP_MODE_RANDOM;
	s_random_duration = 30;

    /* Replace with your application code */
    while (1) 
    {
		while (g_subsec == s_last_subsec) {}
		s_last_subsec = g_subsec;

		// -- brightness adjust
		brightness_set(255, false);
/*		if ((g_subsec & 63) == 0) {
			if (!opto_is_reading()) {
				s_opto_val = opto_read_result();
				opto_read_start();
			}

			brightness_set((s_opto_val < 240) ? s_opto_val : 240, false);
		}*/
		uint8_t adc_val_updated = 0;
		// -- read adc
		if ((s_disp_mode == DISP_MODE_VOLTAGE) && ((g_subsec & 3) == 0)) {
			if (!adc_is_reading()) {
				if (adc_is_reading_what() == ADC_SEL_VBAT) {
					s_adc_value = adc_read_result_16() >> 6;
					avg_val_16_accum(&s_adc_val, s_adc_value);
					adc_val_updated = 1;
					++s_adc_count;
				}
				adc_read_start(ADC_SEL_VBAT);
			}
		}

		// -- read RTC
		if (s_disp_mode == DISP_MODE_RTC)  {
			rtc_read(0, rtcdata, 3);

			// synchronize with seconds change
			if (s_last_sec != rtcdata[0]) {
				s_last_sec = rtcdata[0];
				s_subsec_zero = g_subsec;
			}
		}
		rtc_subsec = (uint8_t)(g_subsec - s_subsec_zero);

		// -- random
		if ((s_disp_mode == DISP_MODE_RANDOM) && ((g_subsec & 0x07) == 1)) {
			s_random_value = (((uint32_t)random() << 16) ^ (random())) & 0x1ffffful;
			if (--s_random_duration < 1) {
				s_random_duration = 0;
				s_disp_mode = DISP_MODE_DIV;
			}
		}

		// -- demo
		if (g_demo_ison) {
			if (g_subsec == 13) {
				if (--g_demo_decr == 0) {
					g_demo_phase++;
					if (g_demo_phase == 1) {
						g_demo_decr = 15;
					} else if (g_demo_phase == 2) {
						s_div_pos = random() % (PRESET_DIV_COUNT - 1);
						s_div_value = pgm_read_dword(&g_preset_div[s_div_pos]);
						s_disp_mode = DISP_MODE_RANDOM;
						s_random_duration = 30;						
						g_demo_decr = 2;
						g_demo_phase = 0;
					}
				}
			}
		}
		// -- read buttons
		btns_update();
		if (btn_state_some_btn_is_clicked() || ((g_subsec & 15) == 2)) {
			switch (s_disp_mode) {
				case DISP_MODE_DIV:
				{
					bool do_change_div = false;
					if (btn_state_is_clicked(1)) {
						if (s_div_pos < 1) {
							s_div_pos = PRESET_DIV_COUNT - 1;
						} else {
							s_div_pos--;
						}
						do_change_div = true;
					} else if (btn_state_is_clicked(0)) {
						if (++s_div_pos >= PRESET_DIV_COUNT) {
							s_div_pos = 0;
						}
						do_change_div = true;
					} else if (btn_state_is_clicked(3)) {
						do_change_div = true;
					} else if (btn_state_is_clicked(2)) {
						s_disp_mode = DISP_MODE_VOLTAGE;
					}
					if (do_change_div) {
						s_div_value = pgm_read_dword(&g_preset_div[s_div_pos]);
						s_disp_mode = DISP_MODE_RANDOM;
						s_random_duration = 30;
					}
				}
				break;
				case DISP_MODE_RANDOM:
				{
					if (btn_state_is_down(3)) {
						s_random_duration = 255;
					}
				}
				break;
				case DISP_MODE_VOLTAGE:
				{
					if (btn_state_is_clicked(2)) {
						g_demo_ison = true;
						g_demo_phase = 0;
						g_demo_decr = 1;
						s_disp_mode = DISP_MODE_RANDOM;
						s_random_duration = 30;
					}
				}
				break;
			}
		}

		// -- set display
		++subsec_input_flasher;
		switch (s_disp_mode) {
			case DISP_MODE_RTC:
			case DISP_MODE_SET_HOUR:
			case DISP_MODE_SET_MIN:
				nixie_set_next_digit(0, rtcdata[0] >> 4);
				nixie_set_next_digit(1, rtcdata[0] & 15);
				/*
				nixie_set_next_digit(0, (rtcdata[2] < 0x10) ? 10 : (rtcdata[2] >> 4));
				nixie_set_next_digit(1, rtcdata[2] & 15);
				nixie_set_next_digit(2, rtcdata[1] >> 4);
				nixie_set_next_digit(3, rtcdata[1] & 15);
				*/
				if (subsec_input_flasher & 0x20) {
					if (s_disp_mode == DISP_MODE_SET_HOUR) {
						nixie_set_next_digit(0, 10);
						nixie_set_next_digit(1, 10);
					} else if (s_disp_mode == DISP_MODE_SET_MIN) {
						nixie_set_next_digit(2, 10);
						nixie_set_next_digit(3, 10);
					}
				}

				break;

			case DISP_MODE_FIXED:
				nixie_set_next_digit(0, 2);
				nixie_set_next_digit(1, 3);
				nixie_set_next_digit(2, 4);
				nixie_set_next_digit(3, 5);
				break;

			case DISP_MODE_VOLTAGE:
				if (!adc_val_updated) break;

				uint32_t adc_val = avg_val_sum(&s_adc_val);
				adc_val *= 302; // 3.3V * 1.5 / 16384 * 1000000

				nixie_set_next_digit(0, adc_val / 1000000 % 10);
				nixie_set_next_digit(1, 10);
				nixie_set_next_digit(2, adc_val / 100000 % 10);
				nixie_set_next_digit(3, adc_val / 10000 % 10);
				nixie_set_next_digit(4, adc_val / 1000 % 10);
				nixie_set_next_digit(5, adc_val / 100 % 10);
				nixie_set_next_digit(6, adc_val / 10 % 10);
				nixie_set_next_digit(7, adc_val / 1 % 10);
				break;

			case DISP_MODE_DIV:
			case DISP_MODE_RANDOM:
				{
					uint32_t disp_val = 0;
					switch (s_disp_mode) {
						case DISP_MODE_DIV: disp_val = s_div_value; break;
						case DISP_MODE_RANDOM: disp_val = s_random_value; break;
					}
					nixie_set_next_digit(0, disp_val / 1000000 % 10);
					nixie_set_next_digit(1, 10);
					nixie_set_next_digit(2, disp_val / 100000 % 10);
					nixie_set_next_digit(3, disp_val / 10000 % 10);
					nixie_set_next_digit(4, disp_val / 1000 % 10);
					nixie_set_next_digit(5, disp_val / 100 % 10);
					nixie_set_next_digit(6, disp_val / 10 % 10);
					nixie_set_next_digit(7, disp_val / 1 % 10);
				}
				break;
		}

    }
}

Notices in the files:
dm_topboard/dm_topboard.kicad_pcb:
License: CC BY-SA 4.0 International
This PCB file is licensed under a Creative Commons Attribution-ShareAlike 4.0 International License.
